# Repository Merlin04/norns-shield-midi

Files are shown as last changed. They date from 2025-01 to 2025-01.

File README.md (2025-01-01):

# norns-shield-midi

norns shield variant with hardware MIDI in/out ([TRS minijack connectors](https://minimidi.world/)), based on the 210330 version of the original [norns shield](https://github.com/monome/norns-shield)

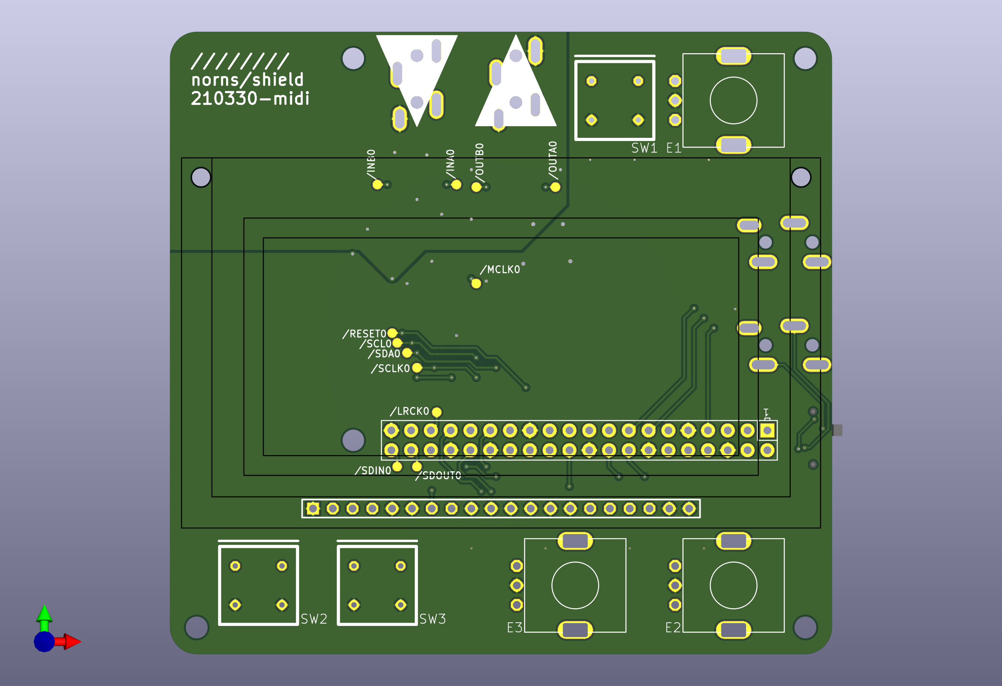
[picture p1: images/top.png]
kicad screenshot of top of PCB


also:
- PCB files ported to kicad
- board outline cleaned up a bit (slightly smaller? probably won't matter)
- MIDI in works with Type-A or Type-B (circuit based on [LPZW auto-crossover MIDI input](https://github.com/kay-lpzw/LPZW_TRS_MIDI), same as shieldXL i think?)
- MIDI out has a switch to choose between Type-A and Type-B

## getting one

this design is currently untested but boards are on the way to me. once i get them, finish assembly, and test one, i'll (try to remember to) update this page. 

i'll have a few extra boards (with SMT components assembled), if you're interested in buying one from me for cost of parts+shipping feel free to reach out - discord username is same as github username, and i'm @m04 on lines

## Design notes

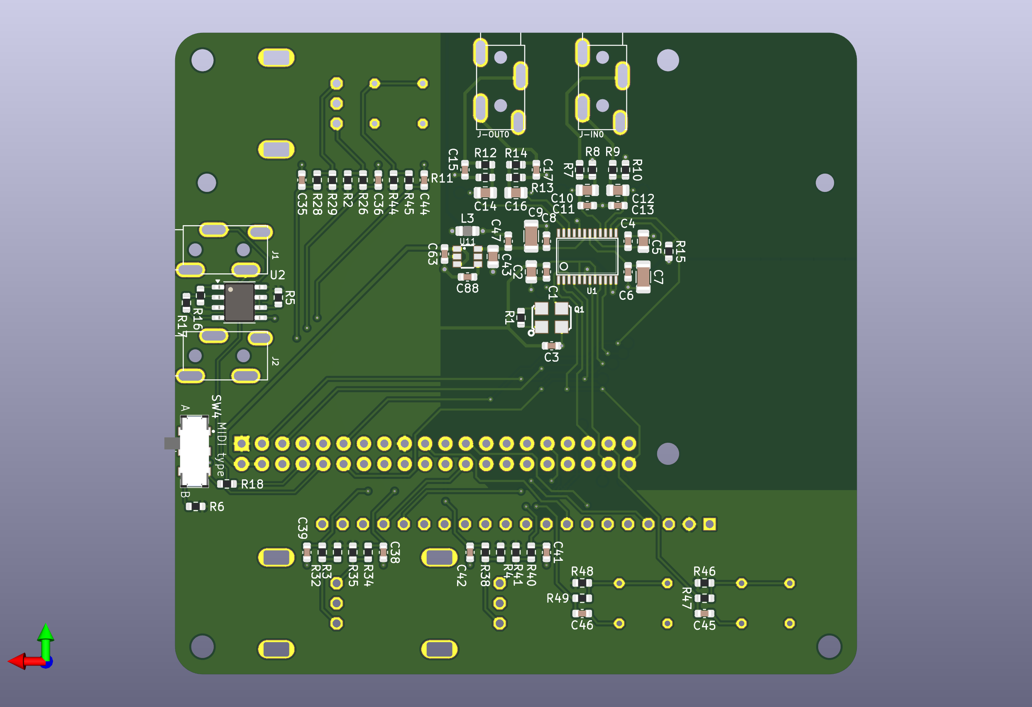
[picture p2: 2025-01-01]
images/bottom.png

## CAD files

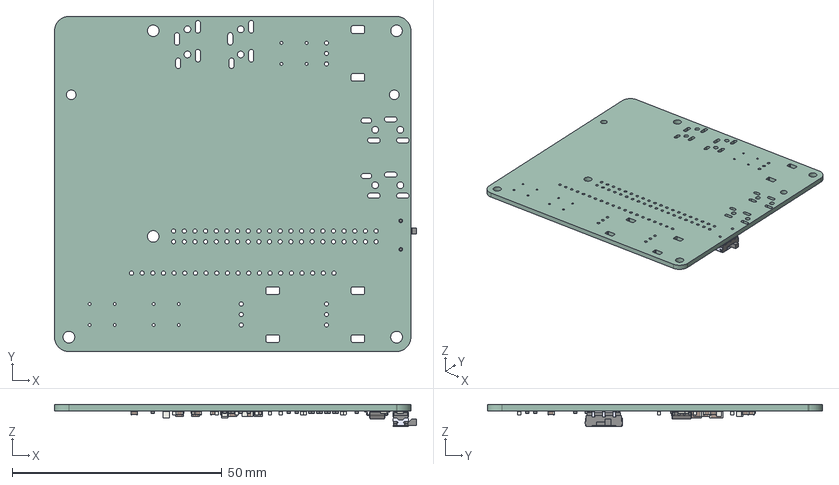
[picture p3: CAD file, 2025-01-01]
norns-shield-210330.step
86.3 x 79.9 x 5.25 mm
R_0603_1608Metric x 33
C_0603_1608Metric x 21
C_0805_2012Metric x 7
C_1206_3216Metric x 2
L_0805_2012Metric
JS102011JAQN
SOIC_8_39x49mm_P127mm
norns-shield-210330_PCB

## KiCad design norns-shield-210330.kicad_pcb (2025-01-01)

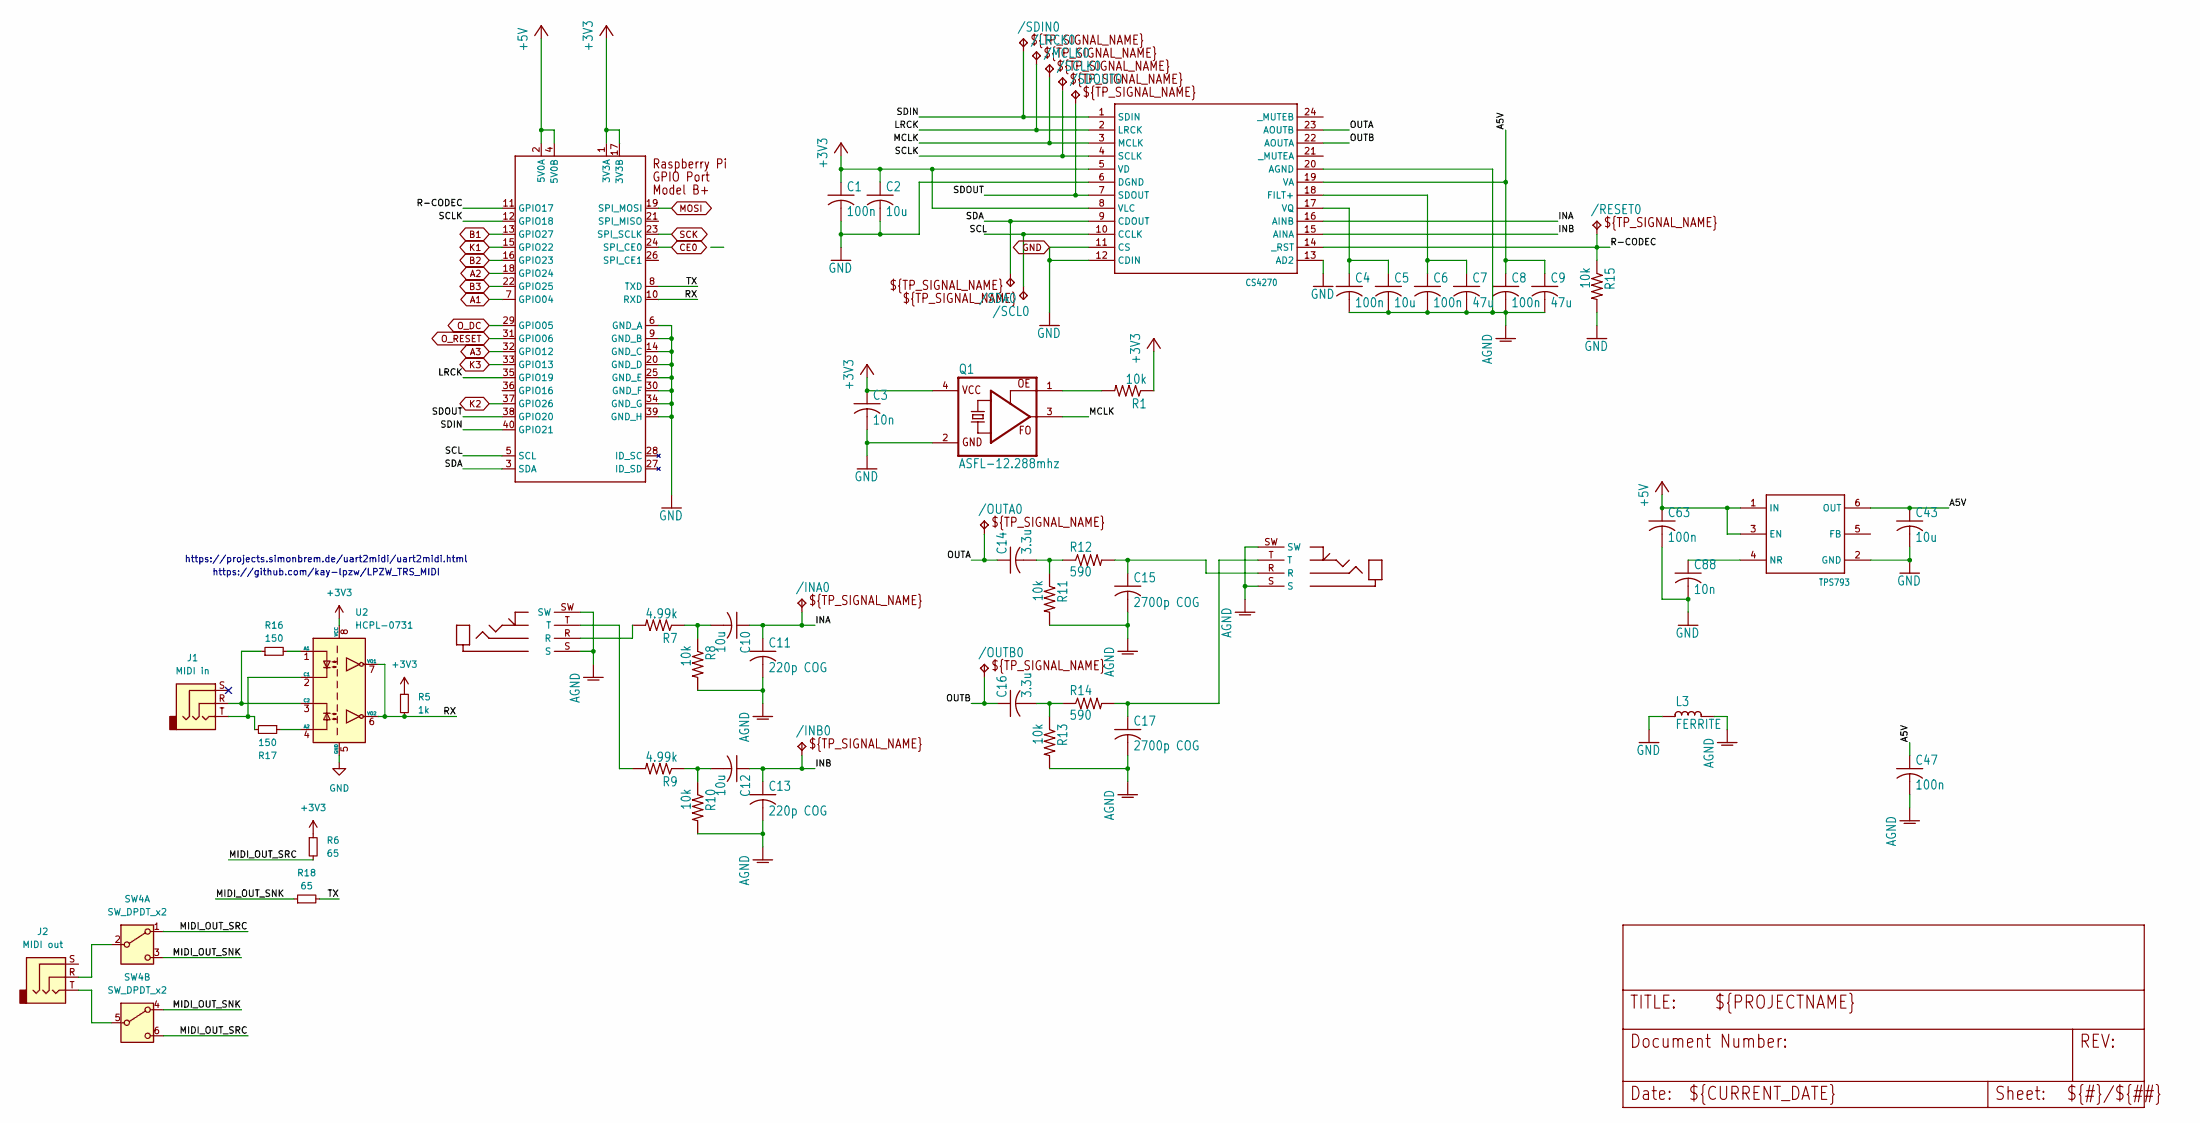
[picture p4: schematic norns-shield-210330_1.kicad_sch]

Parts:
/INA0: TPTP12R; TP12R
/INB0: TPTP12R; TP12R
/LRCK0: TPTP12R; TP12R
/MCLK0: TPTP12R; TP12R
/OUTA0: TPTP12R; TP12R
/OUTB0: TPTP12R; TP12R
/RESET0: TPTP12R; TP12R
/SCL0: TPTP12R; TP12R
/SCLK0: TPTP12R; TP12R
/SDA0: TPTP12R; TP12R
/SDIN0: TPTP12R; TP12R
/SDOUT0: TPTP12R; TP12R
C1, C4, C6, C8, C47, C63: 100n; C_0603_1608Metric
C2, C5, C10, C12, C43: 10u; C_0805_2012Metric
C3, C88: 10n; C_0603_1608Metric
C7, C9: 47u; C_1206_3216Metric
C11, C13: 220p COG; C_0603_1608Metric
C14, C16: 3.3u; C_0805_2012Metric
C15, C17: 2700p COG; C_0603_1608Metric
J1: MIDI in; JACK4832.2330
J2: MIDI out; JACK4832.2330
J-IN0: JACK-TRS-SW; JACK4832.2330
J-OUT0: JACK-TRS-SW; JACK4832.2330
L3: FERRITE; L_0805_2012Metric
Q1: ASFL-12.288mhz; ASF
R1, R8, R10, R11, R13, R15: 10k; R_0603_1608Metric
R5: 1k; R_0603_1608Metric
R6, R18: 65; R_0603_1608Metric
R7, R9: 4.99k; R_0603_1608Metric
R12, R14: 590; R_0603_1608Metric
R16, R17: 150; R_0603_1608Metric
SW4: SW_DPDT_x2; JS202011JAQN
U1: CS4270; TSSOP24
U2: HCPL-0731; SOIC-8_3.9x4.9mm_P1.27mm
U11: TPS793; SSOP6
X1: RASPI_BOARD_B+#_E3; RASPI_BOARD_B+_EDGES_3DRILL

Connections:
+3V3: C1.1, C2.1, C3.1, Q1.4 (VCC), R1.1, R5.1, R6.1, U1.5 (VD), U1.8 (VLC), U2.8 (VCC), X1.1 (3V3A), X1.17 (3V3B); also elsewhere on the board
+5V: C63.1, U11.1 (IN), U11.3 (EN), X1.2 (5V0A), X1.4 (5V0B)
/norns-shield-210330_1/A5V: C8.1, C9.1, C43.1, C47.1, U1.19 (VA), U11.6 (OUT)
/norns-shield-210330_1/INA: /INA0.TP, C10.1, C11.1, U1.16 (AINB)
/norns-shield-210330_1/INB: /INB0.TP, C12.1, C13.1, U1.15 (AINA)
/norns-shield-210330_1/LRCK: /LRCK0.TP, U1.2 (LRCK), X1.35 (GPIO19)
/norns-shield-210330_1/MCLK: /MCLK0.TP, Q1.3 (FO), U1.3 (MCLK)
/norns-shield-210330_1/MIDI_OUT_SNK: R18.1, SW4.3 (C), SW4.4 (A)
/norns-shield-210330_1/MIDI_OUT_SRC: R6.2, SW4.1 (A), SW4.6 (C)
/norns-shield-210330_1/OUTA: /OUTA0.TP, C14.1, U1.23 (AOUTB)
/norns-shield-210330_1/OUTB: /OUTB0.TP, C16.1, U1.22 (AOUTA)
/norns-shield-210330_1/R-CODEC: /RESET0.TP, R15.1, U1.14 (_RST), X1.11 (GPIO17)
/norns-shield-210330_1/RX: R5.2, U2.6 (VO2), U2.7 (VO1), X1.10 (RXD)
/norns-shield-210330_1/SCL: /SCL0.TP, U1.10 (CCLK), X1.5 (SCL)
/norns-shield-210330_1/SCLK: /SCLK0.TP, U1.4 (SCLK), X1.12 (GPIO18)
/norns-shield-210330_1/SDA: /SDA0.TP, U1.9 (CDOUT), X1.3 (SDA)
/norns-shield-210330_1/SDIN: /SDIN0.TP, U1.1 (SDIN), X1.40 (GPIO21)
/norns-shield-210330_1/SDOUT: /SDOUT0.TP, U1.7 (SDOUT), X1.38 (GPIO20)
/norns-shield-210330_1/TX: R18.2, X1.8 (TXD)
A1: X1.7 (GPIO04); also elsewhere on the board
A2: X1.18 (GPIO24); also elsewhere on the board
A3: X1.32 (GPIO12); also elsewhere on the board
AGND: C4.2, C5.2, C6.2, C7.2, C8.2, C9.2, C11.2, C13.2, C15.2, C17.2, C47.2, J-IN0.S, J-IN0.SW, J-OUT0.S, J-OUT0.SW, L3.1, R8.2, R10.2, R11.2, R13.2, U1.20 (AGND)
B1: X1.13 (GPIO27); also elsewhere on the board
B2: X1.16 (GPIO23); also elsewhere on the board
B3: X1.22 (GPIO25); also elsewhere on the board
CE0: X1.24 (SPI_CE0); also elsewhere on the board
GND: C1.2, C2.2, C3.2, C43.2, C63.2, C88.2, L3.2, Q1.2 (GND), R15.2, U1.6 (DGND), U1.11 (CS), U1.12 (CDIN), U1.13 (AD2), U2.5 (GND), U11.2 (GND), X1.6 (GND_A), X1.9 (GND_B), X1.14 (GND_C), X1.20 (GND_D), X1.25 (GND_E), X1.30 (GND_F), X1.34 (GND_G), X1.39 (GND_H); also elsewhere on the board
K1: X1.15 (GPIO22); also elsewhere on the board
K2: X1.37 (GPIO26); also elsewhere on the board
K3: X1.33 (GPIO13); also elsewhere on the board
MOSI: X1.19 (SPI_MOSI); also elsewhere on the board
unnamed: C10.2, R7.1, R8.1
unnamed: C12.2, R9.1, R10.1
unnamed: C14.2, R11.1, R12.1
unnamed: C15.1, J-OUT0.R, R12.2
unnamed: C16.2, R13.1, R14.1
unnamed: C17.1, J-OUT0.T, R14.2
unnamed: J-IN0.R, R7.2
unnamed: J-IN0.T, R9.2
unnamed: Q1.1 (OE), R1.2
unnamed: J2.R, SW4.2 (B)
unnamed: J2.T, SW4.5 (B)
unnamed: C6.1, C7.1, U1.18 (FILT+)
unnamed: C4.1, C5.1, U1.17 (VQ)
unnamed: R16.2, U2.1 (A1)
unnamed: R17.1, U2.4 (A2)
unnamed: J1.T, R17.2, U2.2 (C1)
unnamed: J1.R, R16.1, U2.3 (C2)
unnamed: C88.1, U11.4 (NR)
O_DC: X1.29 (GPIO05); also elsewhere on the board
O_RESET: X1.31 (GPIO06); also elsewhere on the board
SCK: X1.23 (SPI_SCLK); also elsewhere on the board

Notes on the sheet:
https://github.com/kay-lpzw/LPZW_TRS_MIDI
https://projects.simonbrem.de/uart2midi/uart2midi.html

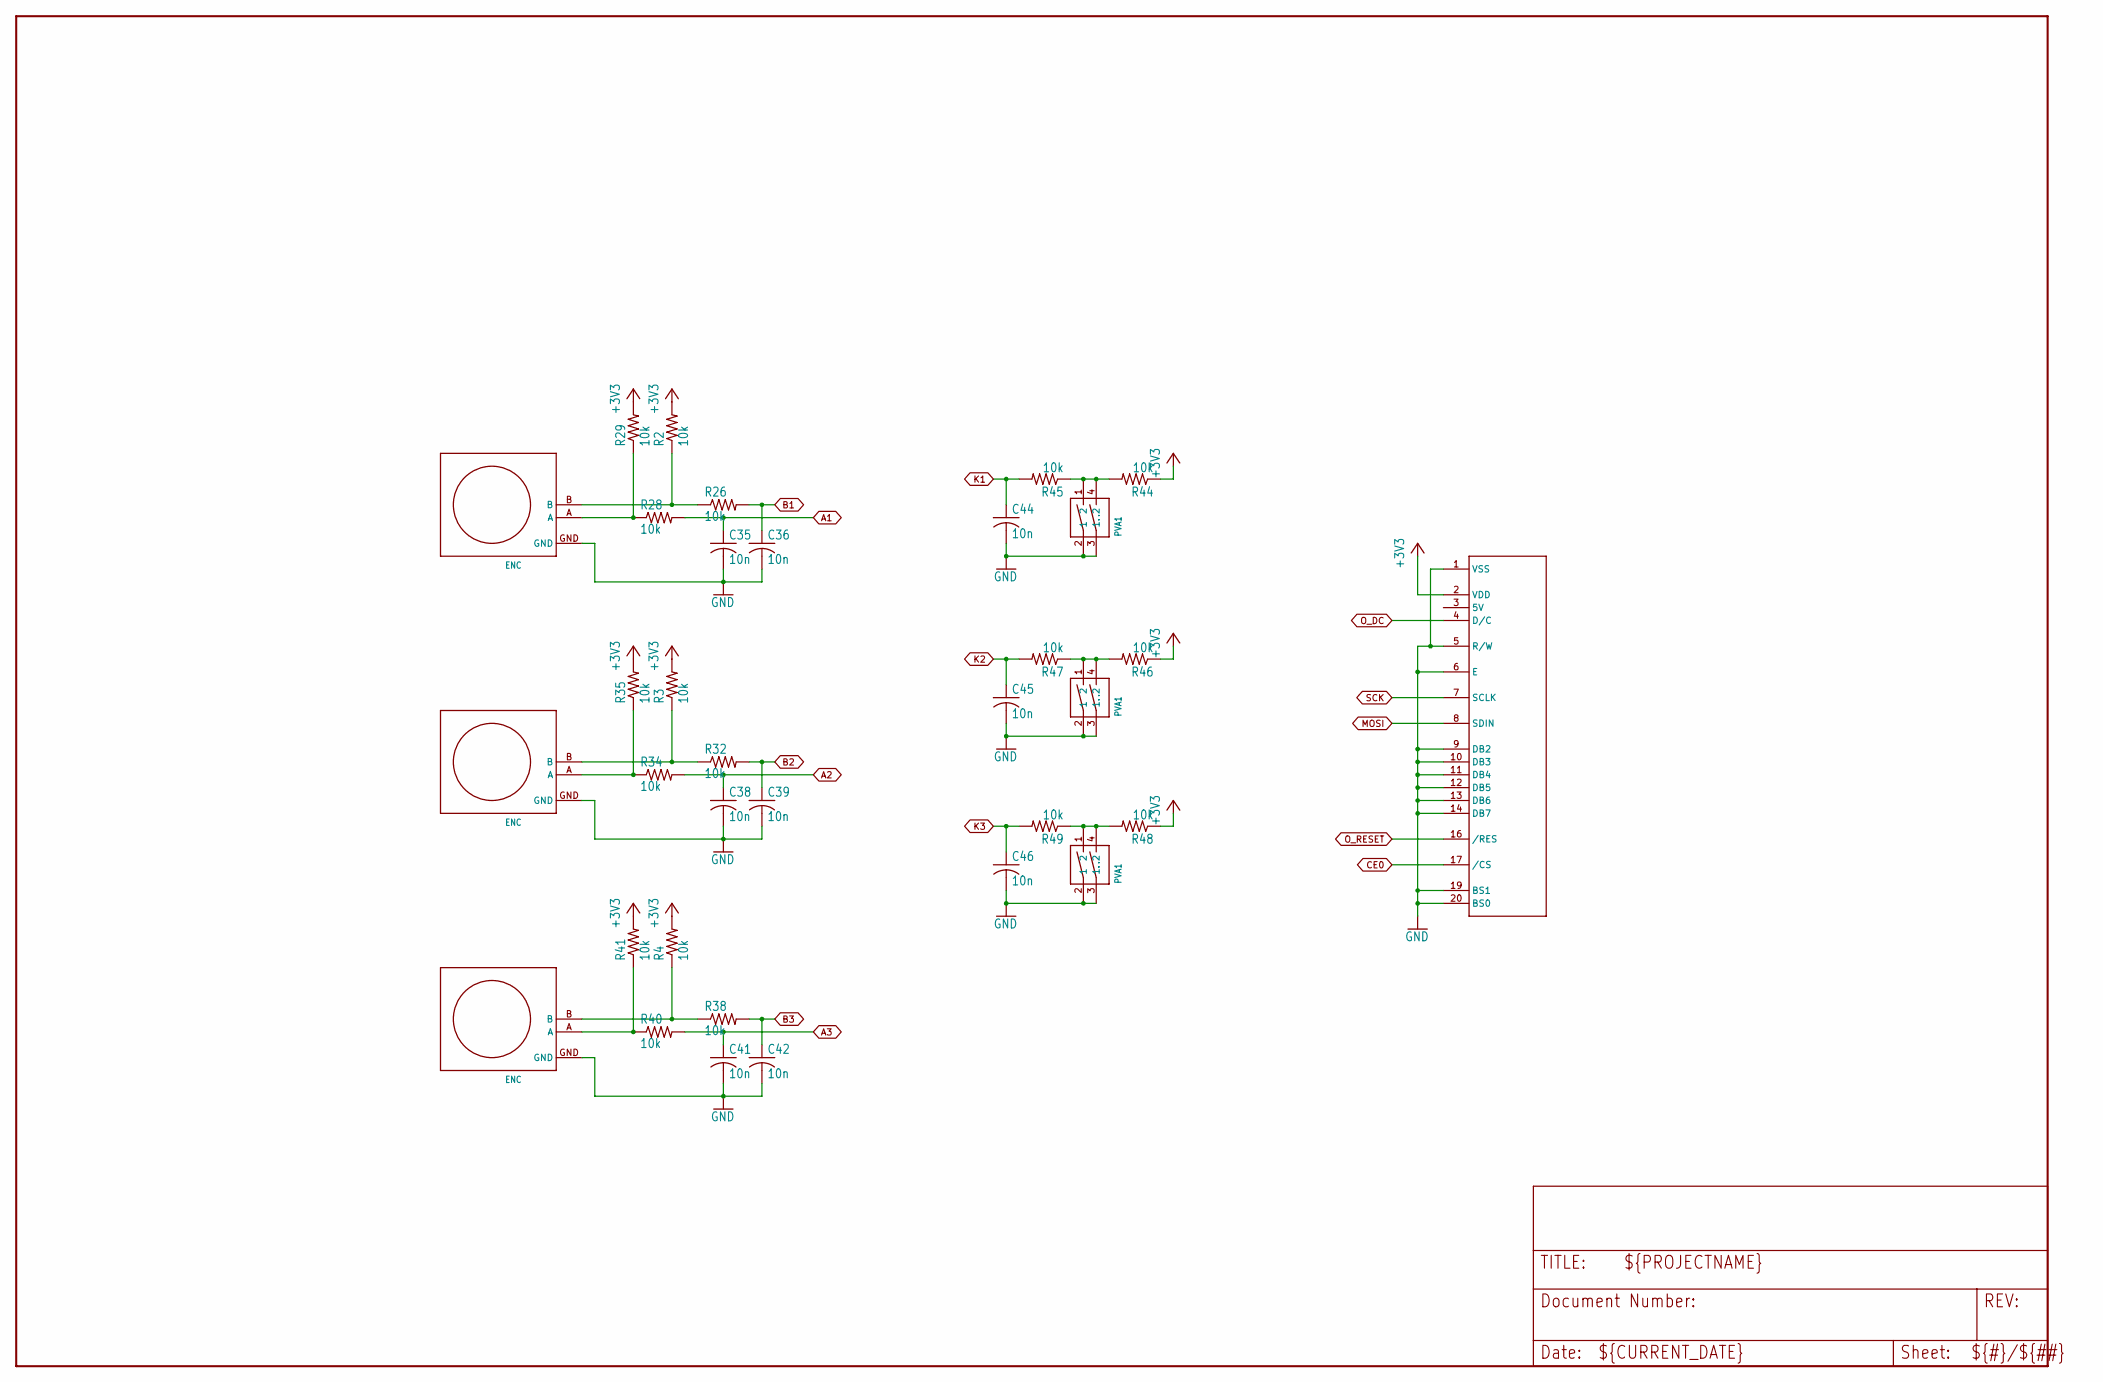
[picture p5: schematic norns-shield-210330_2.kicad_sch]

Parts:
C35, C36, C38, C39, C41, C42, C44, C45, C46: 10n; C_0603_1608Metric
E1, E2, E3: ENC; PEC11RN
R2, R3, R4, R26, R28, R29, R32, R34, R35, R38, R40, R41, R44, R45, R46, R47, R48, R49: 10k; R_0603_1608Metric
SW1, SW2, SW3: PVA1
U$1: OLED128X64; OLED-ALEPH

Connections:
+3V3: R2.2, R3.2, R4.2, R29.2, R35.2, R41.2, R44.1, R46.1, R48.1, U$1.2 (VDD); also elsewhere on the board
A1: C35.1, R28.2; also elsewhere on the board
A2: C38.1, R34.2; also elsewhere on the board
A3: C41.1, R40.2; also elsewhere on the board
B1: C36.1, R26.2; also elsewhere on the board
B2: C39.1, R32.2; also elsewhere on the board
B3: C42.1, R38.2; also elsewhere on the board
CE0: U$1.17 (/CS); also elsewhere on the board
GND: C35.2, C36.2, C38.2, C39.2, C41.2, C42.2, C44.2, C45.2, C46.2, E1.GND, E2.GND, E3.GND, SW1.2 (1), SW1.3 (1.), SW2.2 (1), SW2.3 (1.), SW3.2 (1), SW3.3 (1.), U$1.1 (VSS), U$1.5 (R/W), U$1.6 (E), U$1.9 (DB2), U$1.10 (DB3), U$1.11 (DB4), U$1.12 (DB5), U$1.13 (DB6), U$1.14 (DB7), U$1.19 (BS1), U$1.20 (BS0); also elsewhere on the board
K1: C44.1, R45.2; also elsewhere on the board
K2: C45.1, R47.2; also elsewhere on the board
K3: C46.1, R49.2; also elsewhere on the board
MOSI: U$1.8 (SDIN); also elsewhere on the board
unnamed: E1.A, R28.1, R29.1
unnamed: E1.B, R2.1, R26.1
unnamed: E2.A, R34.1, R35.1
unnamed: E2.B, R3.1, R32.1
unnamed: E3.A, R40.1, R41.1
unnamed: E3.B, R4.1, R38.1
unnamed: R44.2, R45.1, SW1.1 (2), SW1.4 (.2)
unnamed: R46.2, R47.1, SW2.1 (2), SW2.4 (.2)
unnamed: R48.2, R49.1, SW3.1 (2), SW3.4 (.2)
O_DC: U$1.4 (D/C); also elsewhere on the board
O_RESET: U$1.16 (/RES); also elsewhere on the board
SCK: U$1.7 (SCLK); also elsewhere on the board

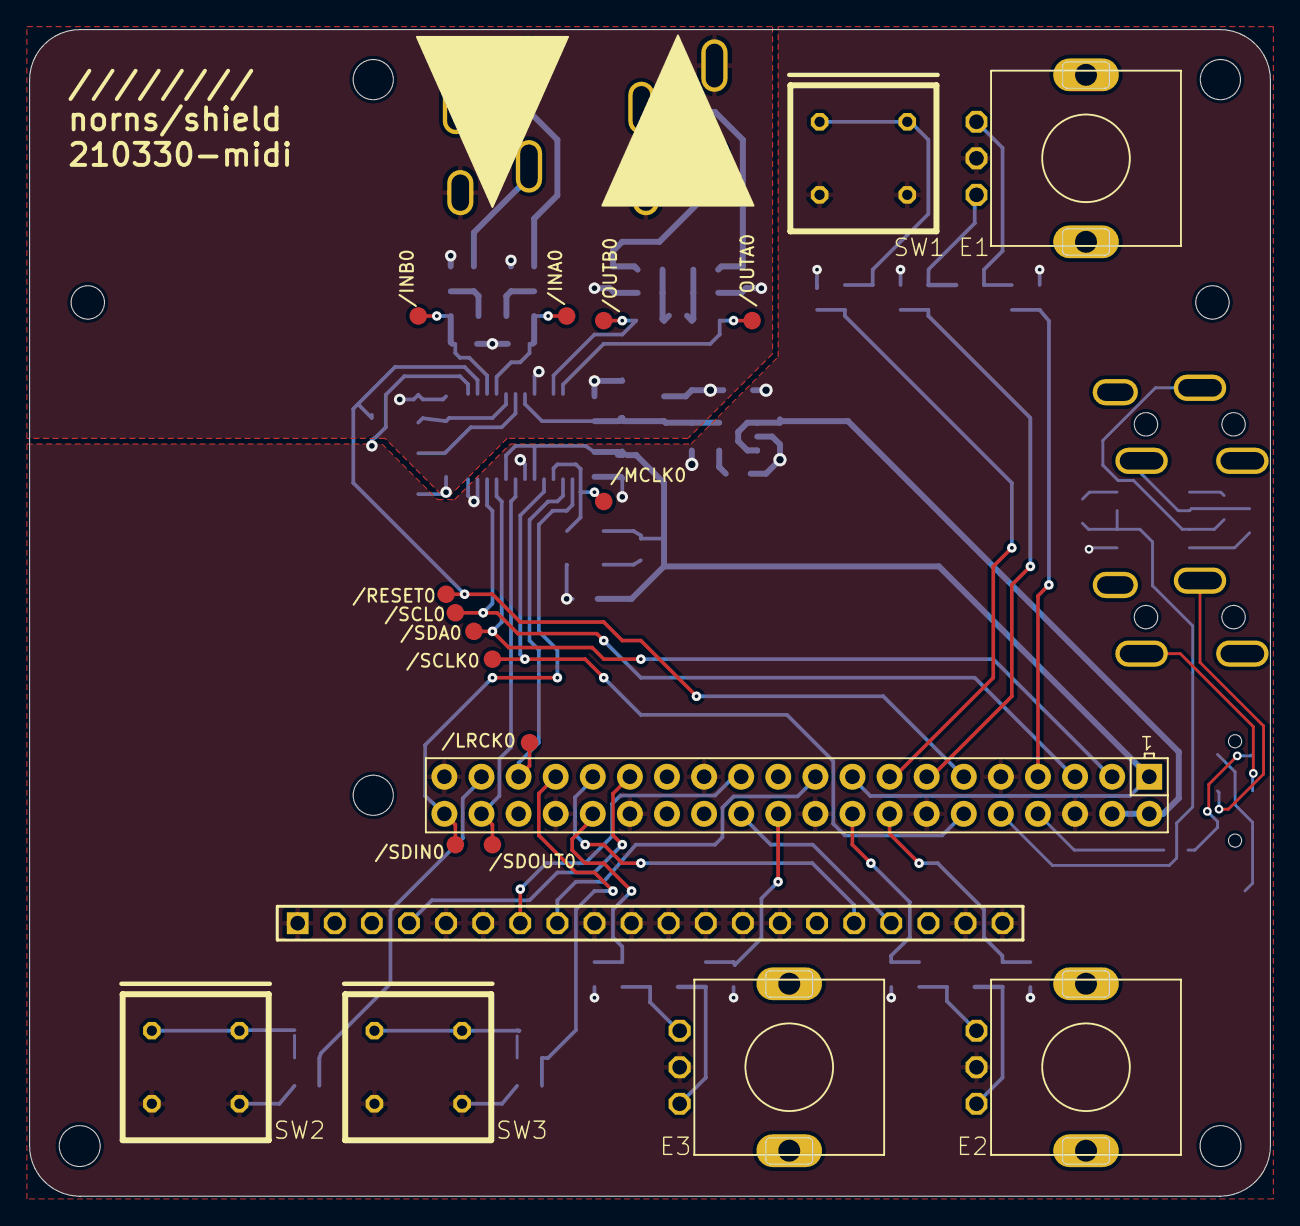
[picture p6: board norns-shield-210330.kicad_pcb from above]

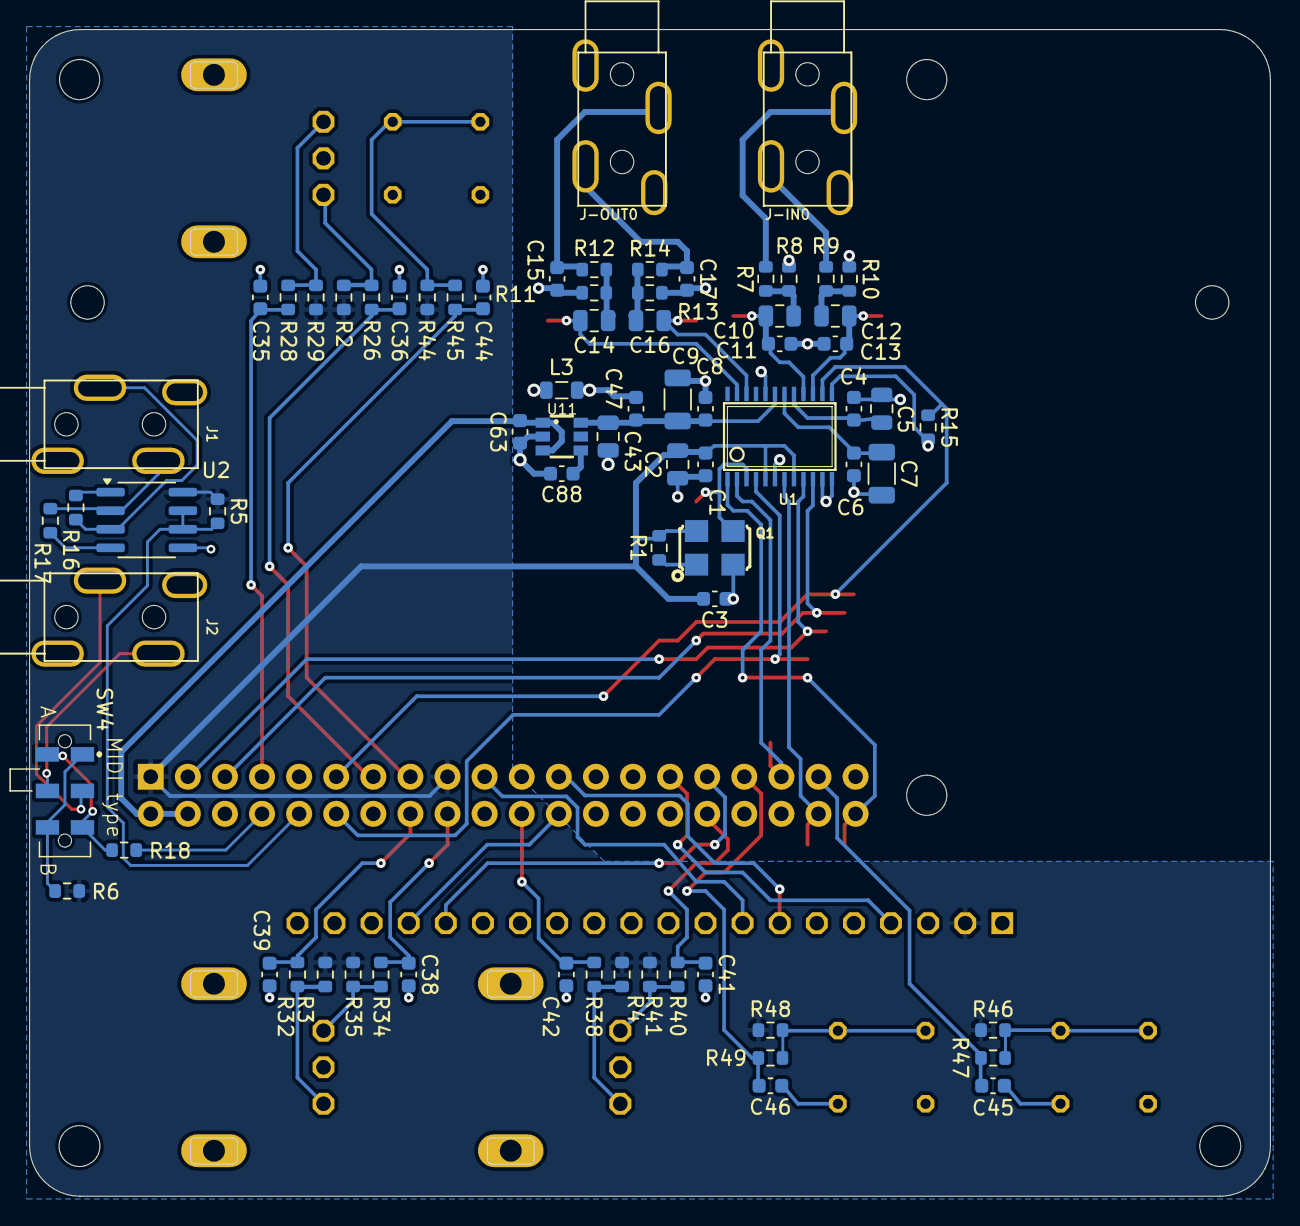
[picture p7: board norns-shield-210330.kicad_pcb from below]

Board: 2 copper layers, 85.0 x 79.9 mm, 95 parts (73 on the bottom side), 62 nets.

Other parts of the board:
@HOLE0, @HOLE1: (no value)
